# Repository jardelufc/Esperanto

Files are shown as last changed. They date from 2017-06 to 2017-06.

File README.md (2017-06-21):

# Esperanto
O OP2MDB  é um produto que permite utilizar aceitadores de
moedas com interface de saídas paralelas simples em
<a href="http://www.royalvendors.com">Vending Machines </a>
com interface MDB (Multi-Drop Bus). Com esta solução, é possível
substituir, a um custo reduzido, aceitadores de moeda com troco, muitas
vezes bastante desgastados pelo uso e pelo tempo, e com taxas de rejeição
de moedas
boas e aceitação de moedas falsas altas, por equipamentos novos,
mais simples e mais baratos. Assim, você pode reduzir o seu TCO
(Total Cost Operation), e o investimento retorna em pouco tempo. OP2MDB  é
um acrônimo de "Output Parallel
to Multi-Drop Bus". O OP2MDB foi desenvolvido para ser utilizado com
aceitadores de moedas
<a href="http://www.luxorvending.com.br/template.php?pagina=automacao.htm">EMP800.00 v4/v5 </a>
da
<a
href="http://www.whberlin.de">wh Munzprufer®</a>.
Para mais informações, leia o <a href="doc/OP2MDB_ManualDoUsuario.pdf">Manual do Usuário</a>.
Entre em <a href="http://www.engelsolutions.com.br/contato.html">contato</a> para
obter cotação deste item.

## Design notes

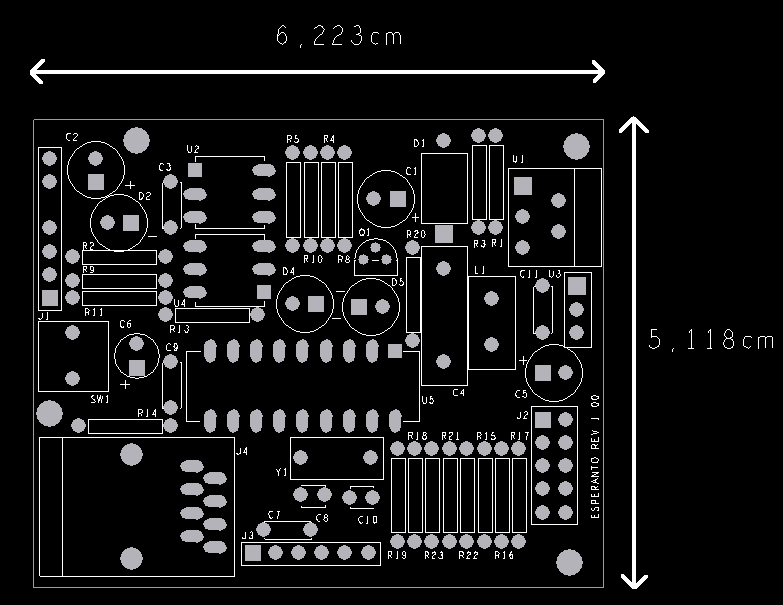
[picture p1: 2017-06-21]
hardware/Esperanto/Additional Files/gerbers/esperanto_versao2.png

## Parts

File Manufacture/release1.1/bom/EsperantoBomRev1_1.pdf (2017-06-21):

Lista de Componentes

Page 1

Montar | PN 1 | PN 2 | PN 3 | PN 4
U1 | SIM | 1 | TI | TL2575-ADJIKV | LM2575TV-AD | LM2575HVT-ADJ/NOPB | LM2575BT | LM2575HVT-ADJ-ND
U2;U4 | SIM | 2 | 4N25M | 4N25A | 4N25 | PC4N250NSZX | 4N25FS-ND
U3 | SIM | 1 | MC7805ACT | LM7805CT | L7805CT | - | - | LM7805CT-ND
U5 | SIM | 1 | PIC16F627A - I/P | - | - | - | - | - | - | PIC16F627A-I/P-ND
Q1 | Transistor | SIM | 1 | BC327 | BC327 | NXP | BC327 | - | - | BC327OS-ND
D1 | Diodo | SIM | 1 | 1N5821 | 1N5821 | 1N5821 | 1N5821-B | 1N5821FS-ND
D2 | LED MINI VERDE | SIM | 1
D4 | LED MINI VERMELHO | SIM | 1
D5 | LED MINI AMARELO | SIM | 1
L1 | SIM | 1
R1 | SIM | 1
R2;R13 | SIM | 2
R3 | SIM | 1
R4 | SIM | 1
R5;R11 | SIM | 2
R10;R14-R19;R21-R23 | SIM | 10
R20 | SIM | 1
C1 | Capacitor EL 330uFx25V | SIM | 1
C2 | Capacitor EL 47uFx50V | SIM | 1
C4 | SIM | 1
C5 | Capacitor EL 47uFx25V | SIM | 1
C6 | Capacitor EL 1uFx10V | SIM | 1
C9;C11 | SIM | 2
J1 | SIM | 1
J2 | Barra de 10 pinos – 5x2 – 100mils | SIM | 1
J3 | Barra de 6 pinos – 100mils | SIM | 1
J4 | NÃO | 1 | A00-108-660-450 | 151-1072-ND
Y1 | NÃO | 1
C3;C7 | NÃO | 2
C8;C10 | NÃO | 2
SW1 | NÃO | 1
R8 | NÃO | 1
Criado por | em 29/03
Revisado por | em 29/05

# Esperanto Rev 1.1

Ref Designator | Descricao | Qty | Manfuacturer 1 | Manufacturer 2 | Manufacturer 3 | Manufacturer 4 | Digikey PN
Reg. Chaveado | On Semi | National | Micrel
Foto acoplador | Fairchild | Toshiba | Avago | Sharp
Reg. Linear 5V | On Semi | Fairchild | STMicroelectonics
Microcontrolador | Microchip
| | | On Semi | Fairchild
| | | On Semi | Fairchild | STMicroelectonics | Diodes Inc

Indutor 330 uH x 0,5A
Resistor mini 10K PTH 1/8W Resistor mini 150R PTH 1/8W Resistor mini 1K PTH 1/8W
Resistor mini 1K PTH 1/8W
Resistor mini 100K PTH 1/8W Resistor mini 4K7 PTH 1/8W Resistor mini 270R PTH 1/8W

Capacitor Pol 0.33uF x 25V

Capacitor Cer 100nF
Barra de 7 pinos – 100 mils – PINO 5 NC
Conector RJ45 | Edac Inc.
Cristal 4 Mhz
Capacitor Cer 100nF
Capacitor Cer 22pF
Reset tact Switch
Resistor mini 47K PTH 1/8W

Jardel
Jardel

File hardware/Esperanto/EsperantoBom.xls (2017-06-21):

Esperanto Rev 1
Ref Designator | Descricao | Load | Qty | Manfuacturer 1 | PN 1 | Manufacturer 2 | PN 2 | Manufacturer 3 | PN 3 | Manufacturer 4 | PN 4 | Digikey PN
U5 | Microcontrolador | L | 1 | Microchip | PIC16F627A - I/P | - | - | - | - | - | - | PIC16F627A-I/P-ND
U2;U4 | Foto acoplador | L | 2 | Fairchild | 4N25M | Toshiba | 4N25A | Avago | 4N25 | Sharp | PC4N250NSZX | 4N25FS-ND
Q1 | Transistor PNP | L | 1 | On Semi | BC327 | Fairchild | BC327 | NXP | BC327 | - | - | BC327OS-ND
U1 | Reg. Chaveado | L | 1 | TI | TL2575-ADJIKV | On Semi | LM2575TV-AD | National | LM2575HVT-ADJ/NOPB | Micrel | LM2575BT | LM2575HVT-ADJ-ND
D1 | Diodo | L | 1 | On Semi | 1N5821 | Fairchild | 1N5821 | STMicroelectonics | 1N5821 | Diodes Inc | 1N5821-B | 1N5821FS-ND
U3 | Reg. Linear 5V | L | 1 | On Semi | MC7805ACT | Fairchild | LM7805CT | STMicroelectonics | L7805CT | - | - | LM7805CT-ND
L1 | Indutor 330 uH – 0,5A | L | 1
R14-R19;R21-R23 | Resistor 4K7 PTH 1/8W | L | 9
R1 | Resistor 5K6 PTH 1/8W | L | 1
R3 | Resistor 1k8 PTH 1/8W | L | 1
R2;R5;R8;R13;R10 | Resistor 150R PTH 1/8W | L | 4
R5;R11 | Resistor 100K PTH 1/8W | L | 2
R9 | Resistor 100r PTH 1/8W | L | 1
R4 | Resistor 1K PTH 1/8W | L | 1
C1 | Capacitor EL 330uFx25V | L | 1
C2;C5 | Capacitor EL 47uFx50V | L | 2
C6 | Capacitor EL 1uFx10V | L | 1
C9 | Capacitor Cer 10nF | L | 1
C7;C11 | Capacitor Cer 100nF | L | 2
C4 | Capacitor Pol 0.33uF | L | 1
D4 | LED VERMELHO | L | 1
D2 | LED AMARELO | L | 1
D5 | LED VERDE | L | 1
J1 | Barra de pinos – 7 | L | 1
J2 | Barra de pinos – 5x2 | L | 1
J3 | Barra de pinos – 6 | L | 1
J4 | Conector RJ45 | NL | 1 | Edac Inc. | A00-108-660-450 |  |  |  |  |  |  | 151-1072-ND
Y1 | Cristal 4 Mhz | NL | 1
C8;C10 | Capacitor Cer 22pF | NL | 2
SW1 | Reset tact Switch | NL | 1
Criado por | Jardel | em 29/03
Revisado por

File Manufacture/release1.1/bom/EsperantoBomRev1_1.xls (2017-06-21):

Esperanto Rev 1.1
Ref Designator | Descricao | Montar | Qty | Manfuacturer 1 | PN 1 | Manufacturer 2 | PN 2 | Manufacturer 3 | PN 3 | Manufacturer 4 | PN 4 | Digikey PN
U1 | Reg. Chaveado | SIM | 1 | TI | TL2575-ADJIKV | On Semi | LM2575TV-AD | National | LM2575HVT-ADJ/NOPB | Micrel | LM2575BT | LM2575HVT-ADJ-ND
U2;U4 | Foto acoplador | SIM | 2 | Fairchild | 4N25M | Toshiba | 4N25A | Avago | 4N25 | Sharp | PC4N250NSZX | 4N25FS-ND
U3 | Reg. Linear 5V | SIM | 1 | On Semi | MC7805ACT | Fairchild | LM7805CT | STMicroelectonics | L7805CT | - | - | LM7805CT-ND
U5 | Microcontrolador | SIM | 1 | Microchip | PIC16F627A - I/P | - | - | - | - | - | - | PIC16F627A-I/P-ND
Q1 | Transistor | SIM | 1 | On Semi | BC327 | Fairchild | BC327 | NXP | BC327 | - | - | BC327OS-ND
D1 | Diodo | SIM | 1 | On Semi | 1N5821 | Fairchild | 1N5821 | STMicroelectonics | 1N5821 | Diodes Inc | 1N5821-B | 1N5821FS-ND
D2 | LED MINI VERDE | SIM | 1
D4 | LED MINI VERMELHO | SIM | 1
D5 | LED MINI AMARELO | SIM | 1
L1 | Indutor 330 uH x 0,5A | SIM | 1
R1 | Resistor mini 10K PTH 1/8W | SIM | 1
R2;R13 | Resistor mini 150R PTH 1/8W | SIM | 2
R3 | Resistor mini 1K PTH 1/8W | SIM | 1
R4 | Resistor mini 1K PTH 1/8W | SIM | 1
R5;R11 | Resistor mini 100K PTH 1/8W | SIM | 2
R10;R14-R19;R21-R23 | Resistor mini 4K7 PTH 1/8W | SIM | 10
R20 | Resistor mini 270R PTH 1/8W | SIM | 1
C1 | Capacitor EL 330uFx25V | SIM | 1
C2 | Capacitor EL 47uFx50V | SIM | 1
C4 | Capacitor Pol 0.33uF x 25V | SIM | 1
C5 | Capacitor EL 47uFx25V | SIM | 1
C6 | Capacitor EL 1uFx10V | SIM | 1
C9;C11 | Capacitor Cer 100nF | SIM | 2
J1 | Barra de 7 pinos – 100 mils – PINO 5 NC | SIM | 1
J2 | Barra de 10 pinos – 5x2 – 100mils | SIM | 1
J3 | Barra de 6 pinos – 100mils | SIM | 1
J4 | Conector RJ45 | NÃO | 1 | Edac Inc. | A00-108-660-450 |  |  |  |  |  |  | 151-1072-ND
Y1 | Cristal 4 Mhz | NÃO | 1
C3;C7 | Capacitor Cer 100nF | NÃO | 2
C8;C10 | Capacitor Cer 22pF | NÃO | 2
SW1 | Reset tact Switch | NÃO | 1
R8 | Resistor mini 47K PTH 1/8W | NÃO | 1
Criado por | Jardel | em 29/03
Revisado por | Jardel | em 29/05

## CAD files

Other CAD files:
hardware/Esperanto/Additional Files/footprint/1N5821/1n5821.psm
hardware/Esperanto/Additional Files/footprint/1n5821.psm
hardware/Esperanto/Additional Files/footprint/2575_TO220/2575_to220.psm
hardware/Esperanto/Additional Files/footprint/2575_to220.psm
hardware/Esperanto/Additional Files/footprint/7805_TO92/7805_to92.psm
hardware/Esperanto/Additional Files/footprint/7805_to92.psm
hardware/Esperanto/Additional Files/footprint/BC327_TO-92/bc327_to-92.psm
hardware/Esperanto/Additional Files/footprint/bc327_to-92.psm
hardware/Esperanto/Additional Files/footprint/cap_cer_100.psm
hardware/Esperanto/Additional Files/footprint/cap_cer_100/cap_cer_100.psm
hardware/Esperanto/Additional Files/footprint/cap_cer_200.psm
hardware/Esperanto/Additional Files/footprint/cap_cer_200/cap_cer_200.psm
hardware/Esperanto/Additional Files/footprint/cap_elec_200mil.psm
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

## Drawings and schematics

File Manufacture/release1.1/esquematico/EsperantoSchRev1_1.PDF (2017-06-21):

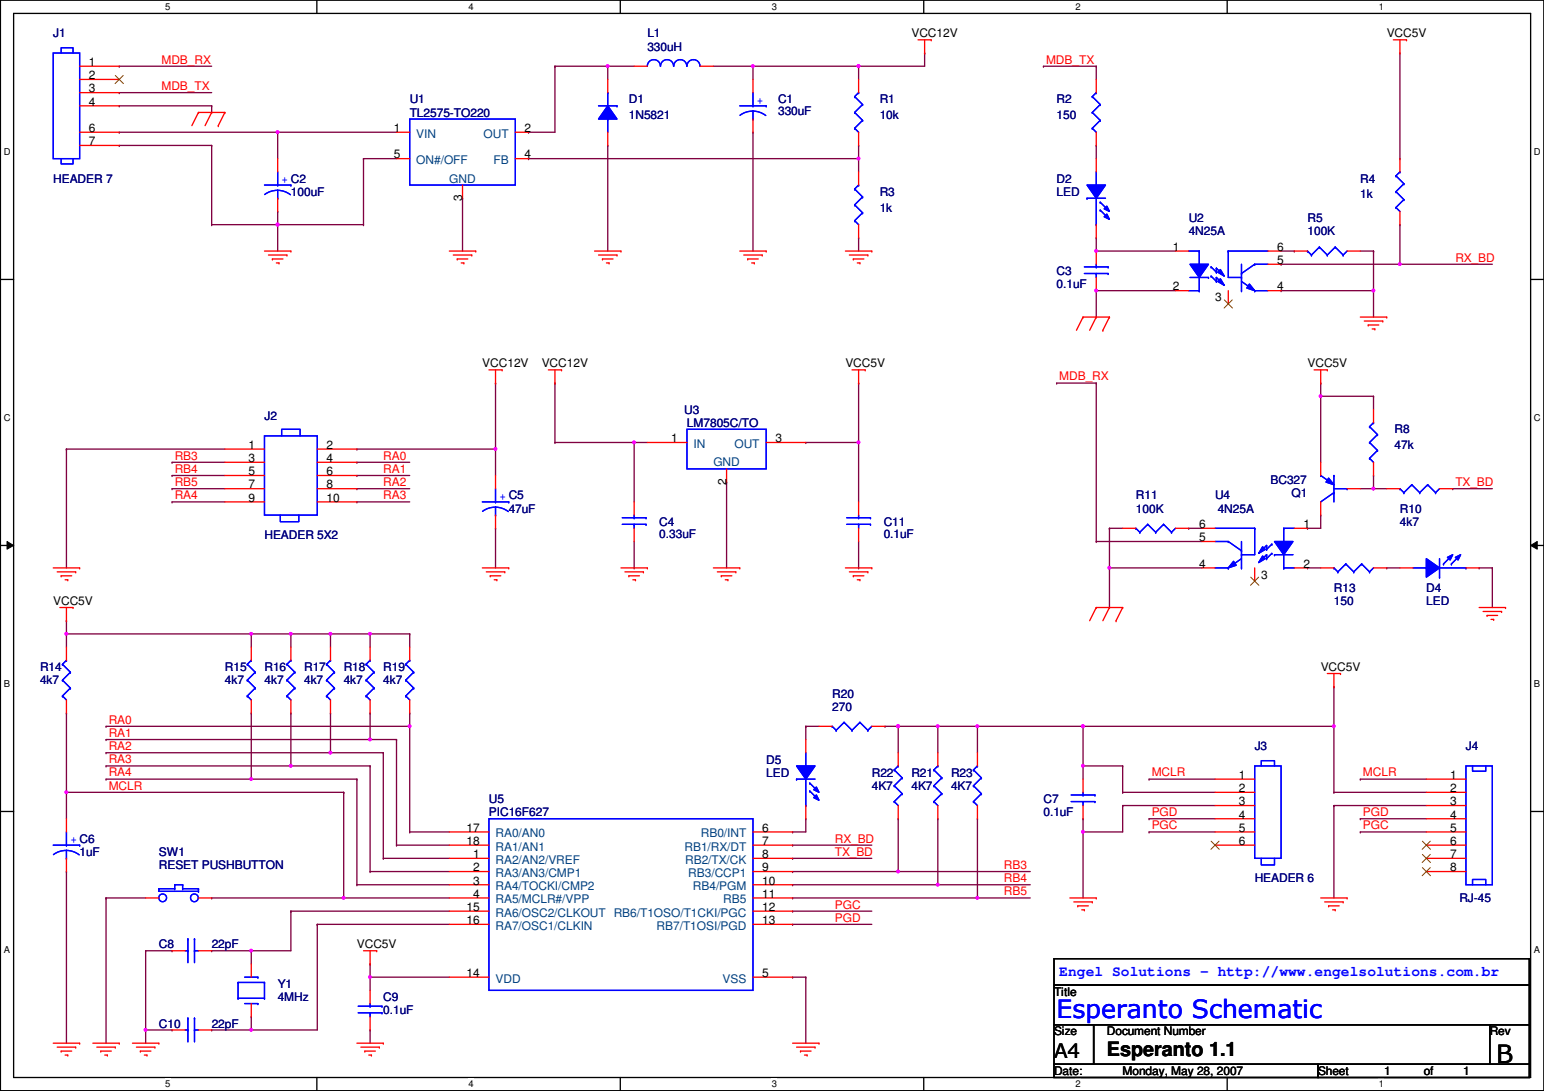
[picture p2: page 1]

Engel Solutions - http://www.engelsolutions.com.br
Esperanto Schematic

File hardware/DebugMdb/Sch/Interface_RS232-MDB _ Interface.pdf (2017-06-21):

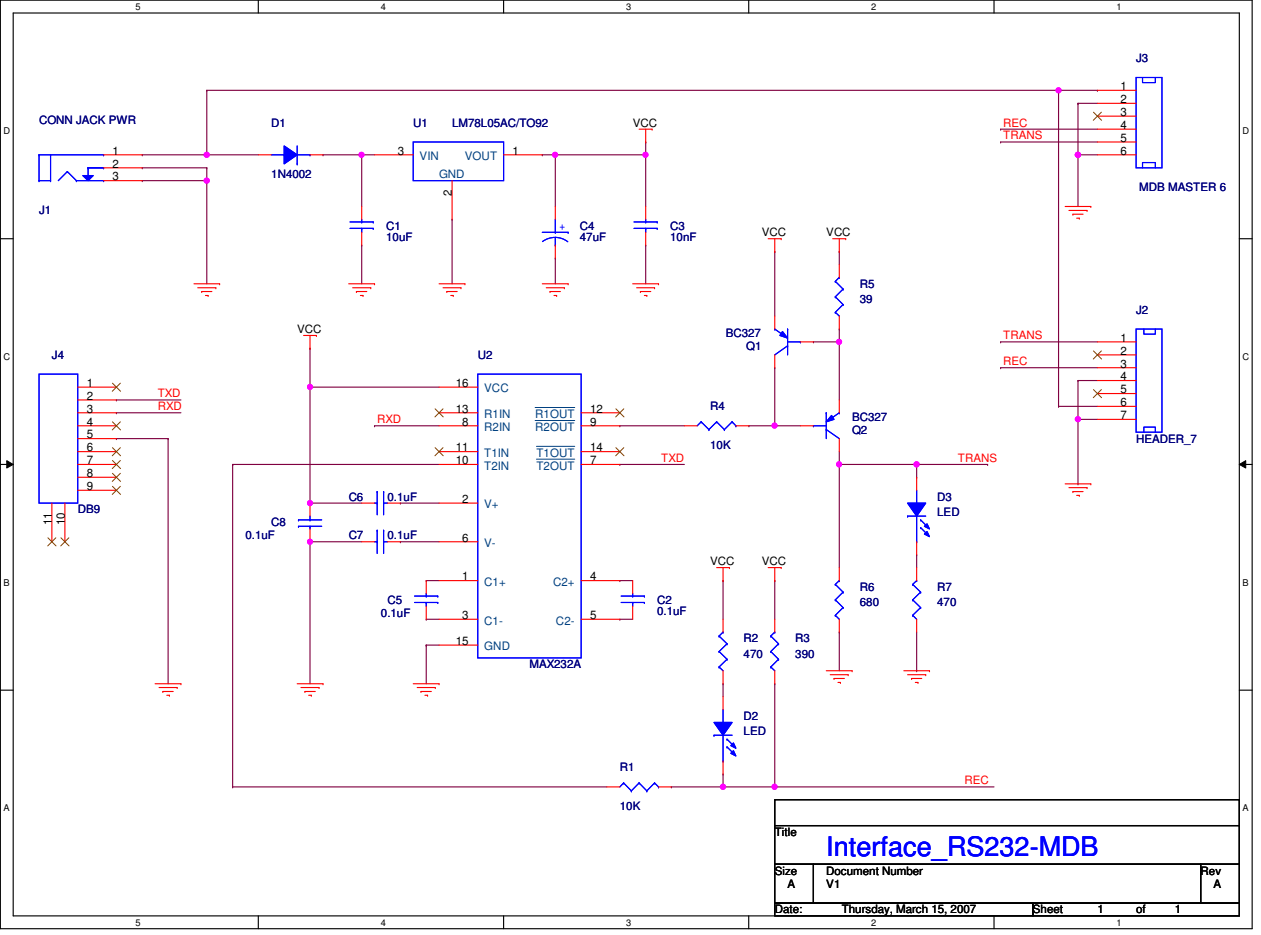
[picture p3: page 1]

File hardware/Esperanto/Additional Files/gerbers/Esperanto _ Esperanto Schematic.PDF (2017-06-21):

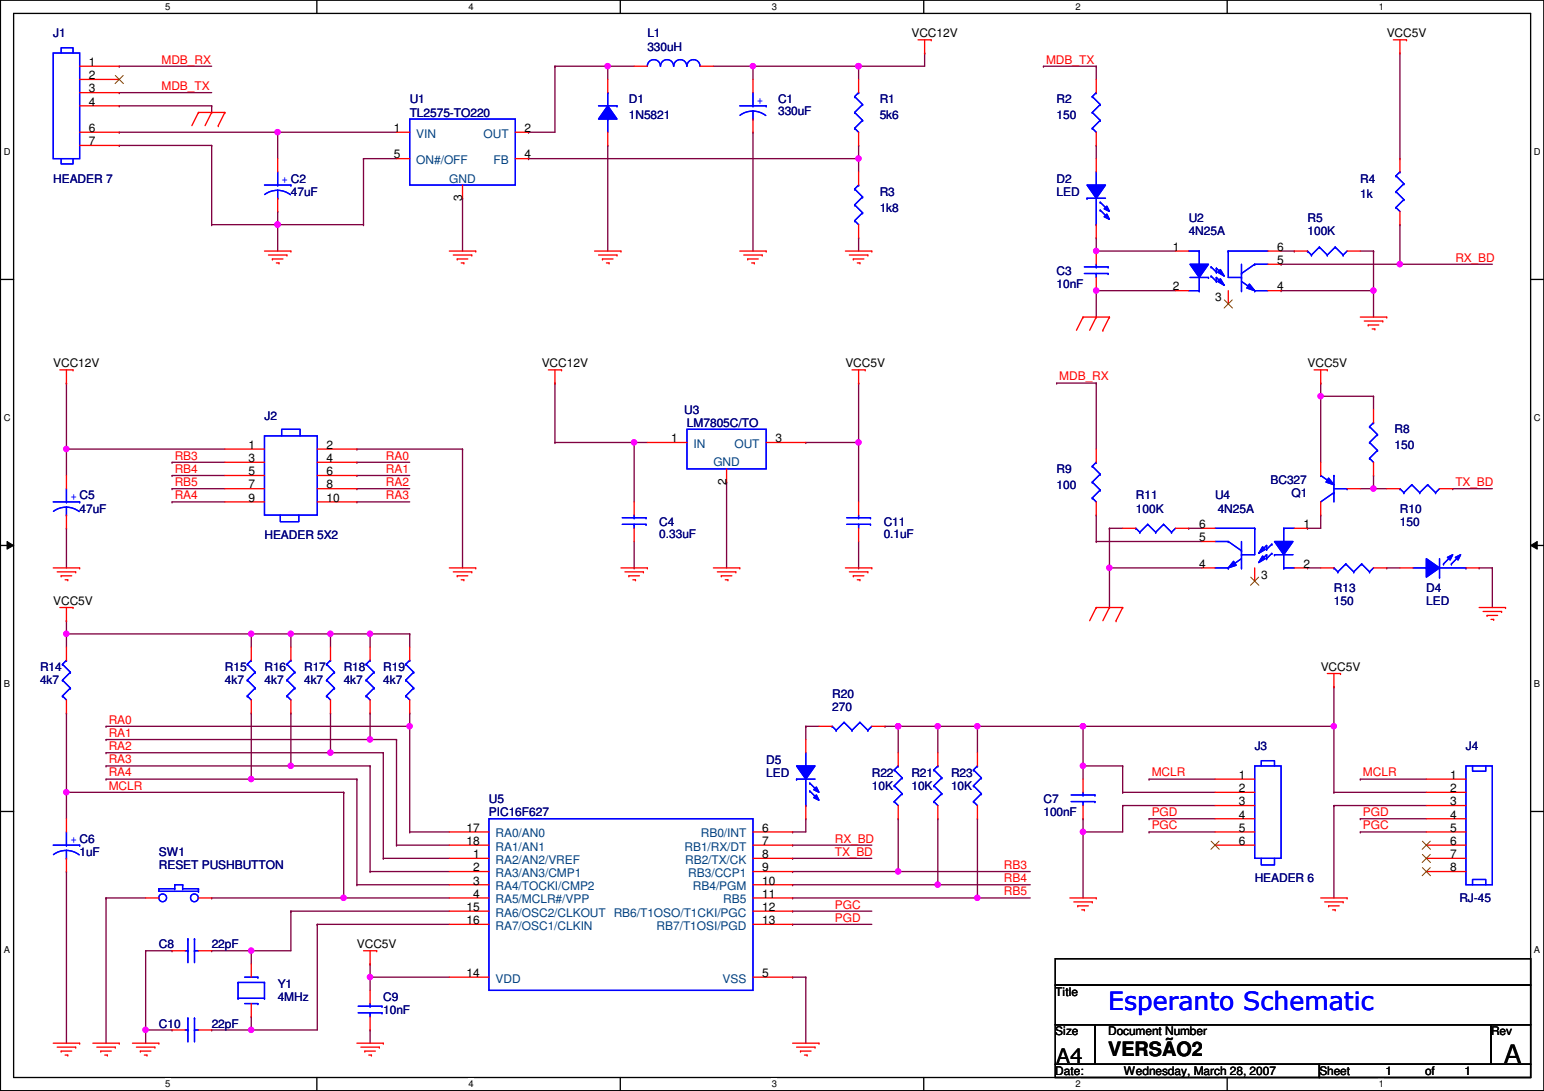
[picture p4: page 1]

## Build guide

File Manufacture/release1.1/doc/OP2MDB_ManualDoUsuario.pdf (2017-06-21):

Engel Solutions – OP2MDB – Manual do Usuário – Rev A.01

## Manual do Usuário - OP2MDB

Engel Solutions - http://www.engelsolutions.com.br

Engel Solutions - OP2MDB – Manual do Usuário – Rev A.01

As informações contidas neste manual foram cuidadosamente verificadas e é acreditado ser inteiramente seguro. A Engel Solutions se reserva o direito de fazer alterações a qualquer momento para melhorar o projeto e fornecer o melhor produto possível. OP2MDB é uma marca da Engel Solutions. Todas as demais marcas e nomes de produtos são propriedade de seus respectivos proprietários.

Engel Solutions - http://www.engelsolutions.com.br | 2/7

## Documentos Referenciados

– | MDB/ICP Version 3.0, NAMA
– | EMP 800.00 ® V4/V5 User's Manual, wh Munzprufer ®

## 1. Precauções de segurança

| É aconselhável seguir as instruções de segurança durante a operação,
manutenção e reparo dos conversores OP2MDB. O não seguimento das instruções de segurança pode resultar na perda de garantia.

Figura 1: Equipamento sensível a ESD (Electrostatic Discharge)

Este equipamento é sensível a descargas eletrostáticas. Todos os procedimentos e uso de equipamentos necessários a manipulação de equipamentos sensíveis a descargas eletrostáticas são cabíveis e aplicáveis.

## 2. Introdução

O OP2MDB é um produto que permite utilizar aceitadores de moedas com interface de saídas paralelas em vending machines com interface MDB (Multi-Drop Bus). OP2MDB é um acrônimo de “Output Parallel to Multi-Drop Bus”.

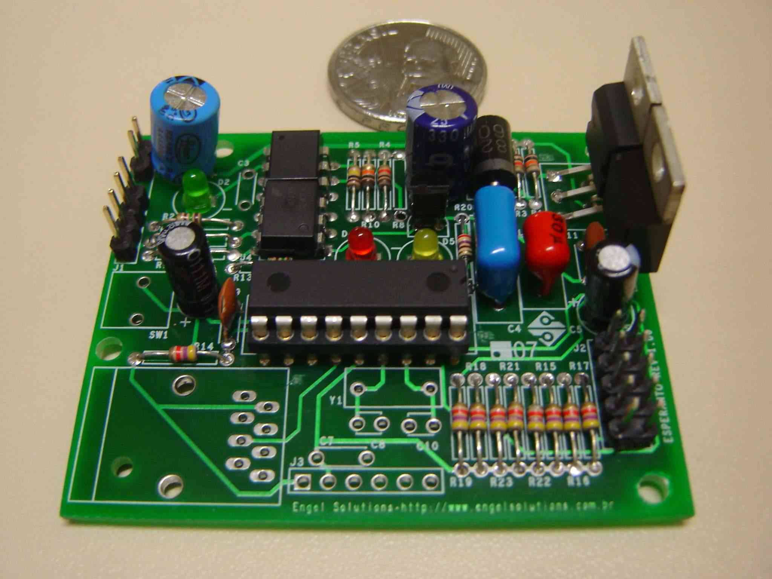
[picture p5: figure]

Figura 2: OP2MDB

## 3. Interfaces

O OP2MDB tem duas interfaces. Uma interface MDB com o VMC (Vending Machine Controller) e outra interface paralela simples com o aceitador de moedas, como mostra a figura abaixo.

Figura 3: Interfaces do OP2MDB

### 3.1 Interface MDB

O OP2MDB se comunica com a vending machine através da interface MDB, exatamente como se este fosse um “coin changer level 3”, ou seja, responde aos comandos enviados ao endereço 08H. O OP2MDB suporta todos os comandos obrigatórios a um changer level 3, mas não suporta nenhum dos comandos opcionais, ou seja:
– | Payout command
– | Extended Diagnostics command
– | Controlled Manual Fill and Payout commands
– | File Transport Layer (FTL) Commands
O hardware e software do OP2MDB são compatíveis, | com a
especificação MDB/ICP Version 3.0. Por default, o OP2MDB tem as seguintes características:
– | Country/Currency Code: 55
– | Coin Scaling Factor – 5
– | Decimal Places - 2
– | Coin Type 1 Credit: 5 centavos
– | Coin Type 2 Credit: 10 centavos
– | Coin Type 3 Credit: 25 centavos
– | Coin Type 4 Credit: 50 centavos
– | Coin Type 5 Credit: 100 centavos
– | Coin Type 6 Credit: 100 centavos (possivelmente uma ficha)

Essas características podem ser alteradas no processo de manufatura, por requisição do cliente.
O conector de interface com o MDB é um header macho polarizado (o 5o. pino é não existente) de sete vias com espaçamento de 100 milésimos de polegadas entre os pinos. Segue abaixo a descrição dos pinos deste conector:
Pino 1 | Master Receive
Pino 2 | N/C
Pino 3 | Master Transmit
Pino 4 | Communications Common
Pino 5 | Não existente
Pino 6 | 34V DC
Pino 7 | DC Power Return

Tabela 1: Pinos do Conector da Interface MDB

O cabo para a interface MDB, totalmente compatível com a especificação MDB, poderá ser adquirido como um acessório (veja item 5).

### 3.2 Interface Paralela

O OP2MDB foi desenvolvido para ser utilizado com aceitadores de moedas EMP800.00 v4/v5 da wh Munzprufer®. O EMP800.00 ® v4/v5 deve estar configurado para emitir um pulso de 100 ms para moeda reconhecida no respectivo pino.
O OP2MDB tem pull ups internos, pois as saídas de coin output do EMP800.00 v4/v5 são coletor aberto.
O conector de interface com o EMP800.00 ® v4/v5 é um header macho de duas linhas por cinco colunas, totalizando 10 pinos, com espaçamento de 100 milésimos de polegadas entre os pinos. Segue abaixo a descrição dos pinos deste conector:
Pino 1 | GND
Pino 2 | VCC - 12V
Pino 3 | Coin Output 5 (Input)
Pino 4 | Coin Output 6 (Input)
Pino 5 | Reject (Output)
Pino 6 | General Blocking (Output)

Pino 7 | Coin Output 1 (Input)
Pino 8 | Coin Output 2 (Input)
Pino 9 | Coin Output 3 (Input)
Pino 10 | Coin Output 4 (Input)

Tabela 2: Pinos do Conector da Interface Paralela com o EMP 800.00

O equipamento poderá ser alterado, sob caráter de projeto especial, de forma a adequar o OP2MDB para interfacear com outros aceitadores de moeda de saídas paralelas.

### 3.3 Sinalização

Os LEDs disponíveis no OP2MDB têm o seguinte significado:

LED AMARELO | Indica que um erro ocorreu
LED VERDE | Recebimento de dado do VMC
LED VERMELHO | Envio de dado ao VMC

Tabela 3: Sinalização

Obs: Alguns erros são passíveis de ocorrer (timeout, checksum etc.). No entanto, o protocolo MDB deverá se recuperar automaticamente de tais erros. Nesses casos, o LED também acenderá.

## 4. Compatibilidade

O OP2MDB foi testado com maquinas de venda automática G-III da Royal Vendors® e aceitador de moedas EMP800.00 ® v4 da wh Munzprufer®.

## 5. Acessórios

O Engel Solutions fornece o cabo de interface MDB, OP2MDBCABLE, como um acessório.

## 6. Especificações Técnicas

Dimensões – 3cm x 6,22 cm x 5,12 cm (A x L x P)

Consumo (com o aceitador conectado) – Nominal 34VDC@80mA, Max 34VDC@350mA
Alimentação – 34VDC
MDB – Nível 3 sem nenhuma das características opcionais Temperatura de operação – +5˚ a +40˚ Celsius

## 7. Suporte

Para suporte contate a Engel Solutions através do e-mail engelsolutions@engelsolutions.com.br.

## 8. Garantia

O produto tem garantia de 1 ano, contado a partir da data de emissão da nota fiscal. Para acionar a garantia, entre em contato através do e-mail engelsolutions@engelsolutions.com.br.

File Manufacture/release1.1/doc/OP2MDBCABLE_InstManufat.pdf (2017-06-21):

Engel Solutions – OP2MDBCABLE – Instruções para Manufatura – Rev A.02

## Instruçoes para Manufatura - OP2MDBCABLE

Engel Solutions - http://www.engelsolutions.com.br

Engel Solutions - OP2MDB – Instruções para Manufatura – Rev A.01

As informações contidas neste documento foram cuidadosamente verificadas e é acreditado ser inteiramente seguro. A Engel Solutions se reserva o direito de fazer alterações a qualquer momento para melhorar o projeto e fornecer o melhor produto possível. OP2MDB é uma marca da Engel Solutions. Todas as demais marcas e nomes de produtos são propriedade de seus respectivos proprietários.

Engel Solutions - http://www.engelsolutions.com.br | 2/4

## 1. Conectores

Em uma extremidade conector Mini-Fit Jr. 6 vias. Duas possibilidades de PN sugerido, mas não fechado (as alternativas mais economicamente viáveis deverão ser escolhidas).

Item | Descriçao | PNs
Connector | Six (6) Circuit Receptacle Housing | Molex P/N 39-01-2060 AMP P/N 106527-6
Terminals | Female Contacts (sockets), Tin | Molex P/N 39-00-0065 AMP P/N 106528-2 or 106529-2
Strain Relief | The strain relief shall not exceed a Maximum Form Factor of 0.85 inch wide x 0.75 inch high x 1.90 inch long, excluding integrated hinges and wire ties. | Molex P/N 15-04-0296 AMP P/N 1375618-1

Na outra, conector tipo header fêmea espaçamento de 100mils 7 vias polarizado (A 5a. via é fechada)

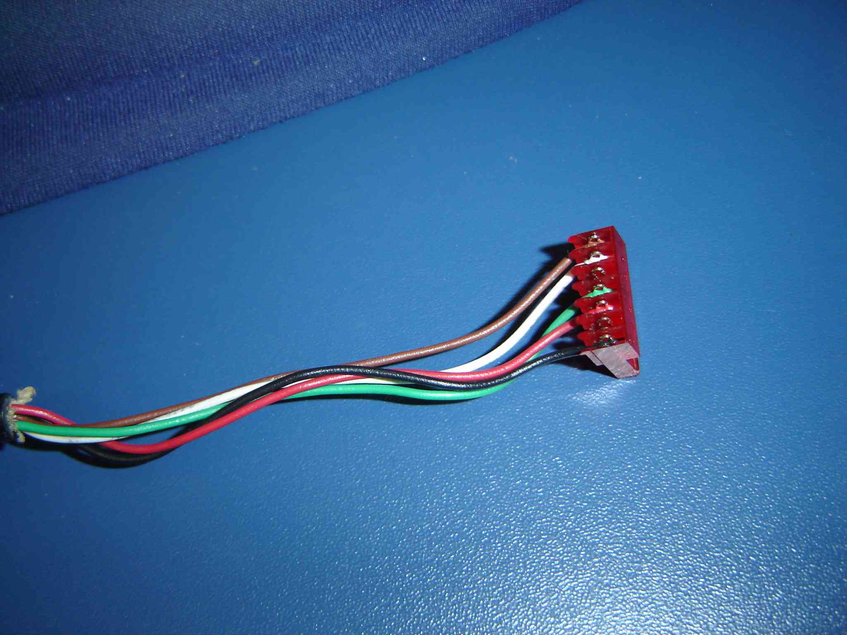
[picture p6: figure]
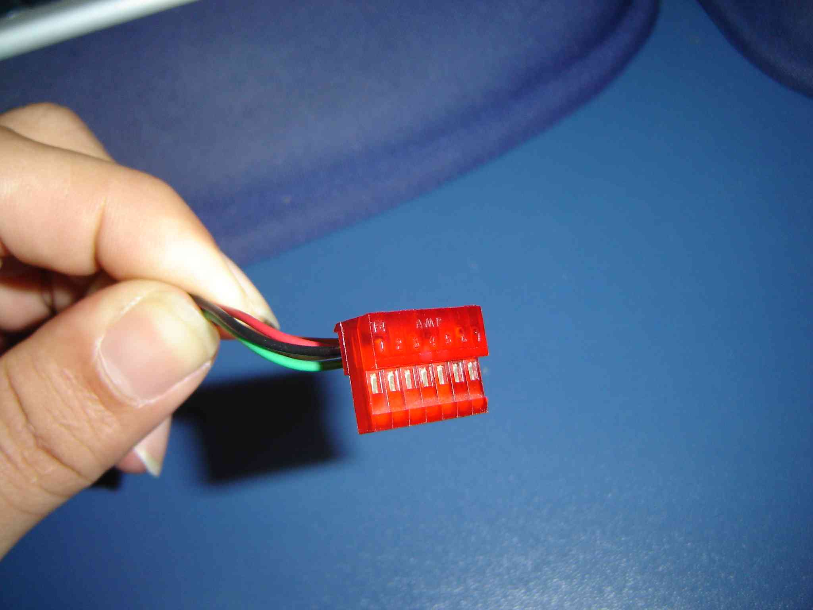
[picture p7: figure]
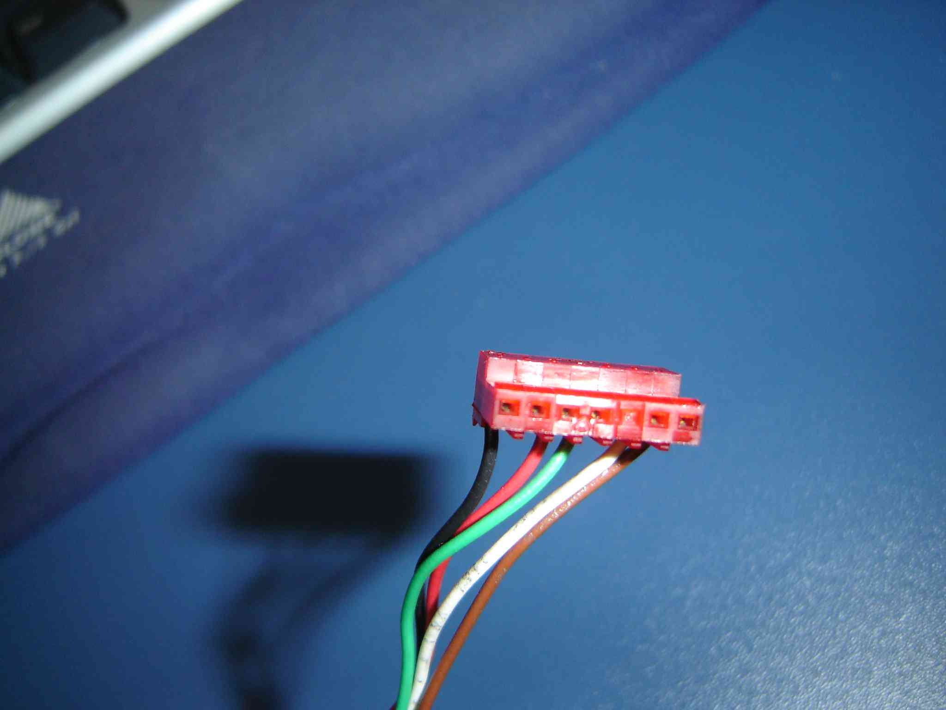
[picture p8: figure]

## 2. Diagrama de Conexões

Conector Header | Conector Mini-Fit Jr.
Pino 1 | Pino 4
Pino 2 | NC
Pino 3 | Pino 5
Pino 4 | Pino 6
Pino 5 | Fechado
Pino 6 | Pino 1
Pino 7 | Pino 2

## 3. Cabo

Cabo de 5 vias. Comprimento total de 15 cm.

## 4. Exemplo

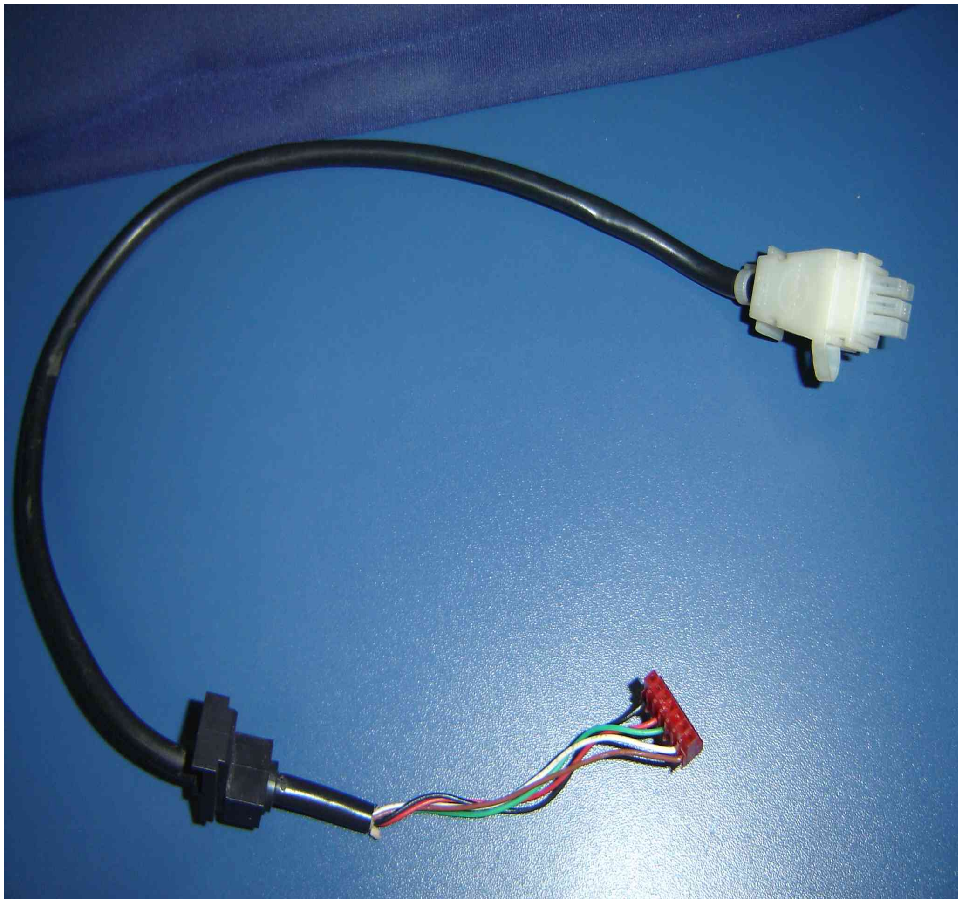
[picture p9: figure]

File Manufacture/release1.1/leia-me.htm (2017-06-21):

## Soluções Tecnológicas Avançadas

Nós desenvolvemos a solução que você precisa e sua empresa fica mais lucrativa.

## Engel Solutions

Tecnologia Aplicada

## OP2MDB - Aplicação em Vending Machines

### Output Parallel to Multi-Drop Bus

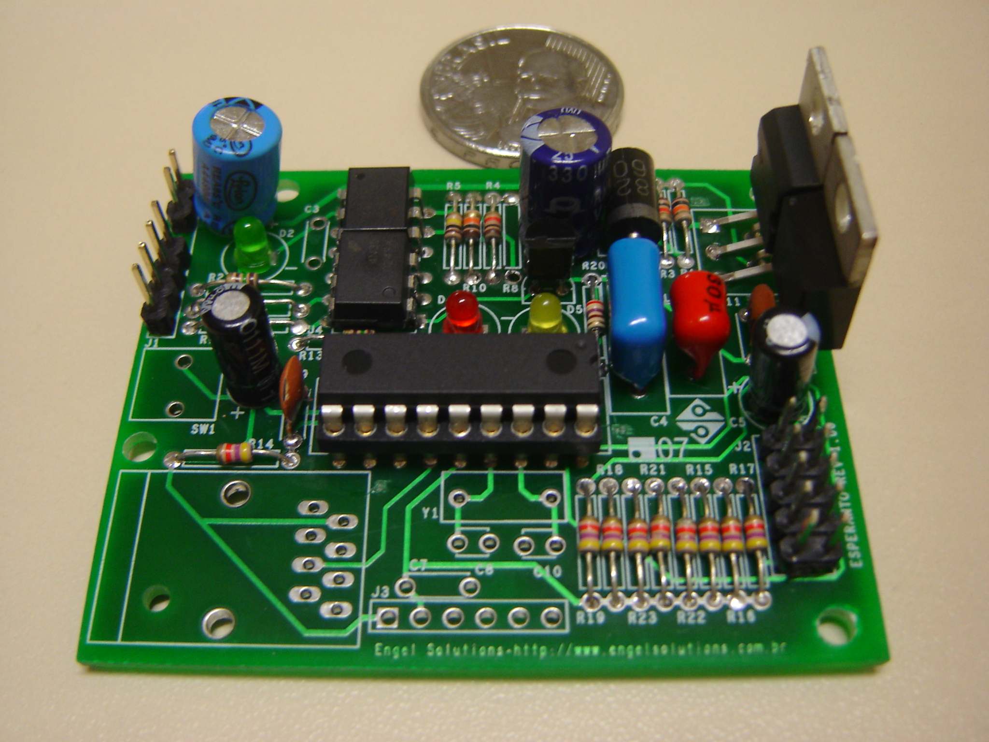
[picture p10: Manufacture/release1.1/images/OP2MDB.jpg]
OP2MDB


O OP2MDB é um produto que permite utilizar aceitadores de moedas com interface de saídas paralelas simples em Vending Machines (http://www.royalvendors.com) com interface MDB (Multi-Drop Bus). Com esta solução, é possível substituir, a um custo reduzido, aceitadores de moeda com troco, muitas vezes bastante desgastados pelo uso e pelo tempo, e com taxas de rejeição de moedas boas e aceitação de moedas falsas altas, por equipamentos novos, mais simples e mais baratos. Assim, você pode reduzir o seu TCO (Total Cost Operation), e o investimento retorna em pouco tempo. OP2MDB é um acrônimo de "Output Parallel to Multi-Drop Bus". O OP2MDB foi desenvolvido para ser utilizado com aceitadores de moedas EMP800.00 v4/v5 (http://www.luxorvending.com.br/template.php?pagina=automacao.htm) da wh Munzprufer® (http://www.whberlin.de). Para mais informações, leia o Manual do Usuário. Entre em contato (http://www.engelsolutions.com.br/contato.html) para obter cotação deste item.

Este CD-ROM contém os arquivos necessário para a manufatura do produto OP2MDB. Para visualizar os documentos, utilize o software Acrobat Reader (http://www.adobe.com). Caso este não esteja instalado em seu computador, utilize o instalador disponível abaixo na seção de instaladores.

### Arquivos de Manufatura

Nome do Arquivo | Descrição
EsperantoSchRev1_1.pdf | Esquema eletrônico da placa OP2MDB versão 1.1
EsperantoGerbersRev1_1.zip | Arquivos Gerbers RS274-X para manufatura da placa de circuito impresso
EsperantoBomRev1_1.pdf | Lista de Componentes
EsperantoBomRev1_1.xls | Lista de Componentes - Formato Excel
esperanto1_1.hex | Firmware do PIC - Versão 1.1
OP2MDBCABLE_InstManufat.pdf | Instruções de manufatura do item OP2MDBCABLE

### Manual

OP2MDB_ManualDoUsuario.pdf | Manual do Usuário do OP2MDB

### Instaladores

AdbeRdr80_pt_BR.exe | Instalador do Adobe Acrobat Reader 8.0

As soluções tecnológicas desenvolvidas pela engel solutions estão sempre alinhadas com as expectativas dos clientes, indo desde simples protótipos para validação funcional de soluções até a geração de produtos que obedeçam rígidas normas internacionais de segurança.

- OP2MDB

## Links

 Engel Solutions (http://www.engelsolutions.com.br)

Copyright © 2006 LGBlue | Design: David Herreman (http://www.free-css-templates.com) | Contact | CSS (http://jigsaw.w3.org/css-validator/check/referer) and XHTML (http://validator.w3.org/check?uri=referer) | Solucija.com | Login (http://webmail.engelsolutions.com.br#)

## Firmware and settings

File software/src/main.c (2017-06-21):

/*
   Por Jardel Silveira (jardel.silveira@engelsolutions.com.br)
   Lib MDB para coin changer
   Criada em 12 de março de 2007
*/

#include <engels.h>
#include <mdb.h>
#include <emp800.h>
#include <serial.h>
#include <htc.h>
#include <pic.h>
#include <timer.h>
#include <stdlib.h>
#include <pic.h>


// Reseta o watchdog
void cleardog(void) {
	#asm
	clrwdt
	#endasm
}
	// Inicializa BITS de configuracao do PIC (fuses)
	__CONFIG (0x1E7C);
	// Oscillator: INTOSC IO ON RA6/RA7
	// Watchdog timer: On
	// Brown Out Detect: Enabled
	// Master clear enable: Enabled
	// Low Voltage Program: Disabled
	// Data EE Read Protect Enabled
	// Code protec: On


// Define se é uma versão de demonstração
//#define __DEMO__

#ifdef __DEMO__
	// Variável não volátil que conta o número de boots efetuados pelo 
eeprom unsigned char runtimes = 0;
#endif

// Variável auxiliar para operação na variável armazenada na EEPROM
BYTE cAux;
void main (void) 
{
  	// Inicializa o TIMER 1 
	init_timer();
  	// Inicializa portos e variáveis relacionados ao EMP 800
  	emp800_init();
  	// Inicializa porta serial para 9600 bps 9 bits e 1 stop bit
  	init_comms();
  	// Inicializa variáveis relacionadas à interface MDB
  	mdb_init();


	#ifdef __DEMO__
	// Lê da EEPROM para a RAM
  	cAux = runtimes;
	// Caso tenha excedido o número máximo de boots permitidos
  	if(cAux==0) {
		// Coloca o LED para piscar
		LedBlink();
		while(1) {
			// Roda a máquina de estados do LED
	    	LedEngine();
			// Reseta o WatchDog
	    	cleardog();
 		}
   }
	// Lê da EEPROM para a RAM
   cAux = runtimes;
	// Decrementa variável de 1 boot
   cAux--;
	// Escreve da RAM para a EEPROM
   runtimes = cAux;
#endif
   // Loop Infinito
   while(1) {
		// Roda máquina de estados do protocolo MDB
      mdb_engine();
		// Roda máquina de estados da interface paralela com o EMP800
      emp800_engine();
		// Roda máquina de estados do LED
	#ifdef LEDLIB
      LedEngine();
	#endif
		// Resetao WatchDog
		cleardog();
   }
}

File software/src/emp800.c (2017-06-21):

/*
   Por Jardel Silveira (jardel.silveira@engelsolutions.com.br)
   Lib MDB para coin changer
   Criada em 24 de março de 2007
*/


#include <string.h>
#include <engels.h>
#include <emp800.h>
#include <htc.h>
#include <pic.h>
#include <timer.h>


// Variável contadoras de moedas recebidas e de moedas enviadas ao mdb master
BYTE acCountCoin[6];
// Variável para armazenamento do estado dos canais das moedas
static BYTE acStateCoin[6];
// Variáveis para controle da led engine
static BYTE cLed1, cLedState,cLedDiff;



// Inicialização dos ios e variáveis relativos ao moedeiro e relativo ao LED
void   emp800_init(void) {
	static BYTE cData;
	// Inicializa PORTA em modo de I/O
	cData = CMCON;
	cData |= 0x07;
	CMCON = cData;
	TRISA = 0xFD;   // 1111 1101
       // RA7 =  1 // OSC2 - UNUSED
       // RA6 =  1 // OSC1 - UNUSED
       // RA5 =  1 // MCLR - UNUSED
       // RA4 =  1 // COINOUTPUT3
       // RA3 =  1 // COINOUTPUT4
       // RA2 =  1 // COINOUTPUT2
       // RA1 =  0 // GENBLOCKING
       // RA0 =  1 // COINOUTPUT6
   TRISB = 0xEE;   // 1111 1010
       // RB7 =  1 // PGD - UNUSED
       // RB6 =  1 // PGC  - UNUSED
       // RB5 =  1 // COINOUTPUT1
       // RB4 =  0 // REJECT - UNUSED
       // RB3 =  1 // COINOUTPUT5
       // RB2 =  1 // TX
       // RB1 =  1 // RX
       // RB0 =  0 // LED
	emp800_disableAccept();// Default Doesn´t accept coins
   LED = 1;          // Default LED is off
	cLedState = 0;
	// Inicializa variável do estado das moedas
	memset(acStateCoin, WAITINGFALLING,6);
	//Inicializa variável de contagem das moedas
	memset(acCountCoin, 0x00,6);
}



void emp800_engine(void) {
	
	static BYTE cTimeCoin[6];
   static BYTE cCoinLine;
   static BYTE i;

   static BYTE cDataA, cDataB;
	//Lê o porto A
	cDataA = PORTA;
	//Lê o portoB
   cDataB = PORTB;
	// Inicializa cCoinLine com todos bits setados
	 cCoinLine = 0xFF;
	// Carrrega o estado do canal 1 no BIT0 de cCoinLine
	if(!(cDataB & BIT5)) 
		cCoinLine &= ~BIT0;
	// Carrrega o estado do canal 2 no BIT1 de cCoinLine
	if(!(cDataA & BIT2)) 
		cCoinLine &= ~BIT1;
	// Carrrega o estado do canal 3 no BIT2 de cCoinLine
	if(!(cDataA & BIT4)) 
		cCoinLine &= ~BIT2;
	// Carrrega o estado do canal 4 no BIT3 de cCoinLine
	if(!(cDataA & BIT3)) 
		cCoinLine &= ~BIT3;
	// Carrrega o estado do canal 5 no BIT4 de cCoinLine
	if(!(cDataB & BIT3)) 
		cCoinLine &= ~BIT4;
	// Carrrega o estado do canal 6 no BIT5 de cCoinLine
	if(!(cDataA & BIT0)) 
		cCoinLine &= ~BIT5;

// Captura o estado do BIT0 de cCoinLine
#define LINESTATE (cCoinLine&0x01)

	for (i =0; i < 6; i++) {
	   switch (acStateCoin[i]) {
      	// Aguarda descida do sinal que indica reconhecimento de moeda
         case WAITINGFALLING:
         	// Caso o sinal desça, muda o estado da máquina e zera contador de tempo
            if(!LINESTATE) {
            	acStateCoin[i] = WAITINGRISING;
               cTimeCoin[i] = getTimeCounter();
            }
         	break;
            // Aguarda subida do sinal após 100 ms
  			case WAITINGRISING:
         	// Verifica se o contador não excedeu o valor máximo
         	if(ElapsedTime(cTimeCoin[i]) > MAXTIMECOIN) {
         		acStateCoin[i] = WAITINGFALLING;
					//LedOn();
            	break;
         	}
         	// Verifica se o sinal subiu
         	if(LINESTATE) {
         		// Retorna ao estado default
            	acStateCoin[i] = WAITINGFALLING;
            	// Caso o sinal tenha ficado baixo por tempo mínimo, incrementa contador de moeda
            	if(ElapsedTime(cTimeCoin[i]) > MINTIMECOIN) 
            		acCountCoin[i]++;
				}
      		break;
		} //END SWITCH
		// Rola 1 bit para a esquerda de modo a pegar o estado do proximo canal
      cCoinLine >>= 1;
	} // END FOR
}
#ifdef LEDLIB
//Máquina de estados do LED
void LedEngine (void) {
	
	// No caso de o LED estar no estado de apagado, nao faz nada
	if(cLedState==0) 
		return;
	// Captura o tempo passado em ms desde de a última vez que o estado do LED mudou
	cLedDiff = ElapsedTime (cLed1);
	// Verifica se o tempo decorrido excede 250ms
	if(cLedDiff > 250) {
		// Caso o LED esteja em estado de ligado, apaga-o e muda para estado de apagado
		if(cLedState==1) {
      	LED = 1;
        	cLedState=0;
		}
		// Caso o LED esteja em estado de BLINK, inicializa novamente o contador de tempo e inverte a situacao atual do LED
		else if(cLedState==BLINK) {
			cLed1 = getTimeCounter();
			LED = !LED;
		}
	}
}
// Acende o LED, Muda seu estado para ligado e inicializar variavel contadora de tempo
void LedOn (void) {
   LED = 0;
   cLedState = 1;
   cLed1 = getTimeCounter () ;
}
// Coloca o LED em estado de BLINK e inicializa variável contadora de tempo
void LedBlink(void) {
	cLedState = BLINK;
	cLed1 = getTimeCounter();
}
#endif
